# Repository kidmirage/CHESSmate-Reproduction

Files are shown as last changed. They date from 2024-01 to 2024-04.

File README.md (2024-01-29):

# CHESSmate-Reproduction
The plan is to make a reproduction of the dedicated chess computer CHESSmate released by Commodore in 1978.

CHESSmate was developed by Peter Jennings, author of the KIM-1 MicroChess program, under contract with Commodore International. The CHESSmate’s hardware is based on the venerable KIM-1, but the ROMs are loaded with a custom MicroChess 1.5 image not the KIM’s monitor.

CHESSmate units are extremely hard to find, understandable given that 45 years have passed since they were introduced. My hope is to build a working CHESSmate computer using modern fabrication techniques and components, and to produce a comprehensive set of instructions with modeling files (PCB, 3D Print, etc.) so that anyone else could make one as well.

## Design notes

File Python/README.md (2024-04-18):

This is a software only CHESSmate emulator written in Python. As far as I know the only dependency is that PyGame must be available. I have tested this on:

Raspberry Pi 4 - Python 3.11.2 - PyGame 2.1.2

Windows - Python 3.10.5 - PyGame 2.1.2

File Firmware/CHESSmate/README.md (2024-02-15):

This Arduino Pro Mini version of the CHESSmate emulator is officialy deprecated. The Arduino was just too slow.

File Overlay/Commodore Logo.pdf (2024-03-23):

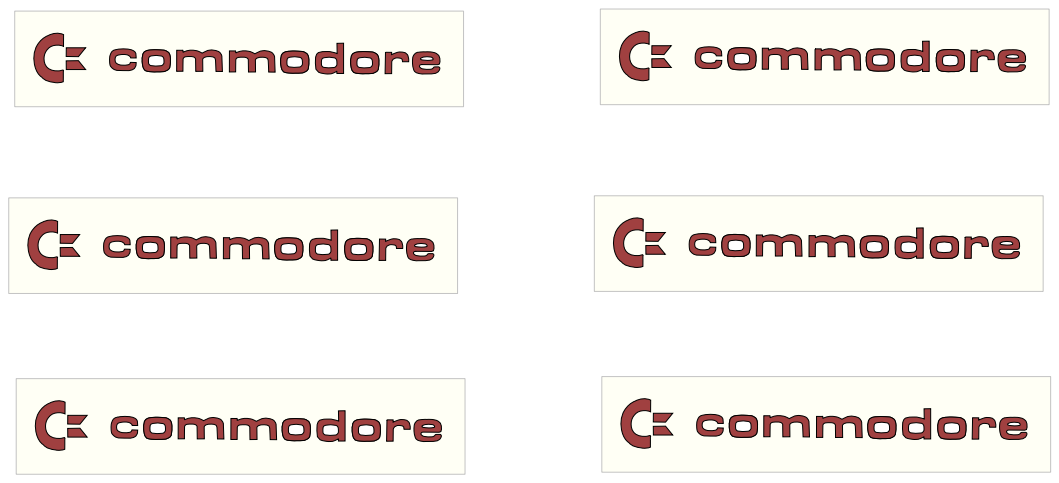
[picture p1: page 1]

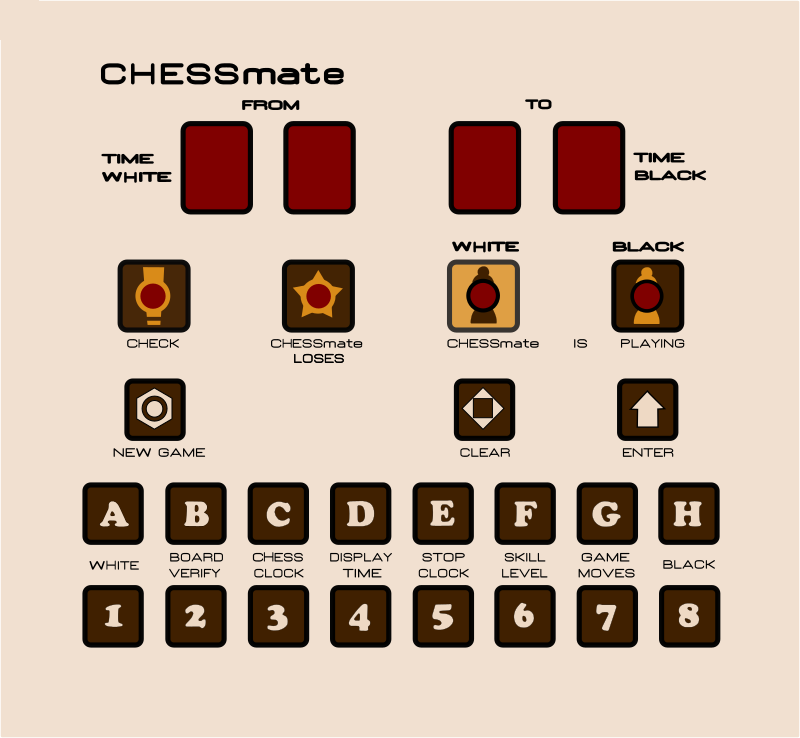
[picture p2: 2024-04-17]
Python/Images/Membrane Image (800x738).png

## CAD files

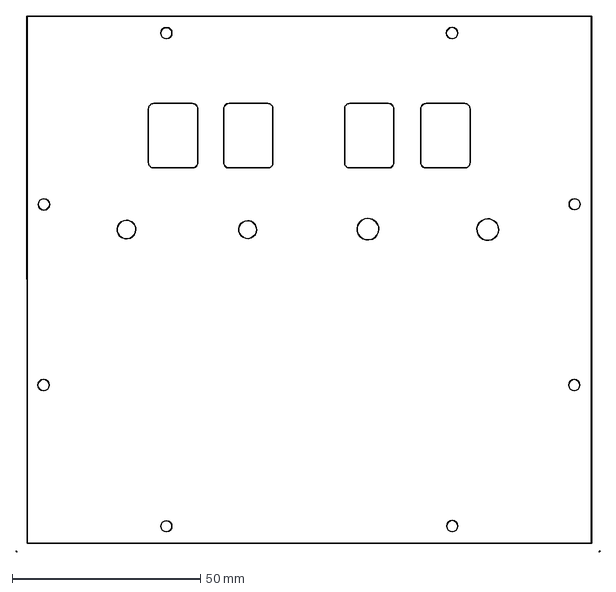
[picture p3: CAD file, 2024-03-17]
Models/CM_Chessmate Cutouts.dxf
155.2 x 142.4 mm

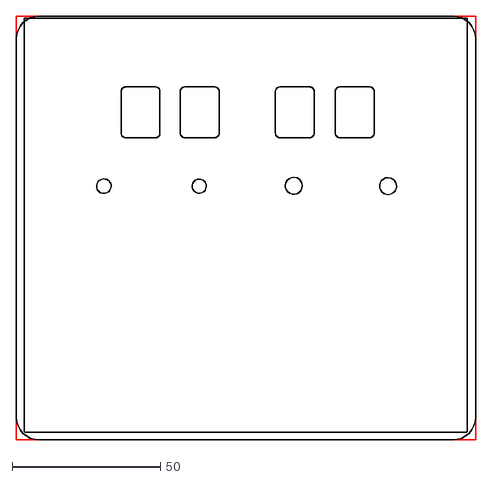
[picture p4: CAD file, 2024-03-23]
Overlay/Membrane Cutouts.dxf
155.2 x 143.0

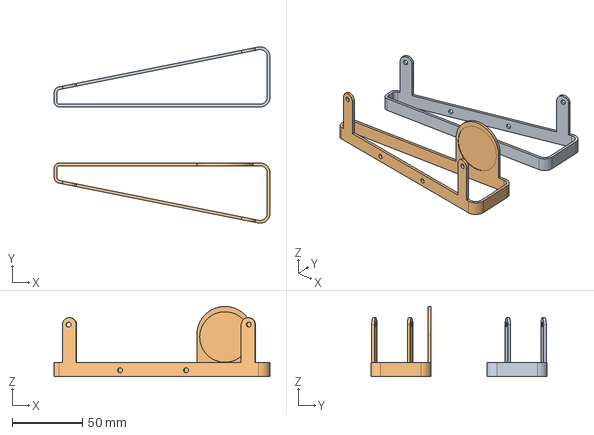
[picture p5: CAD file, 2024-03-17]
Models/CM_Minimal Stand 2.step
154.0 x 125.8 x 50.0 mm

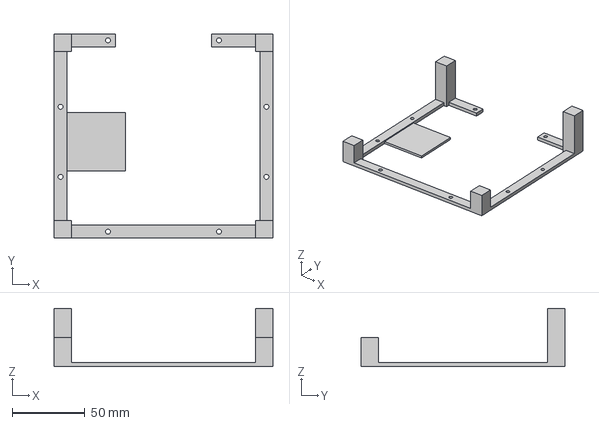
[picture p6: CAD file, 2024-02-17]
Models/CM_Minimal Stand.step
150.0 x 140.0 x 40.0 mm

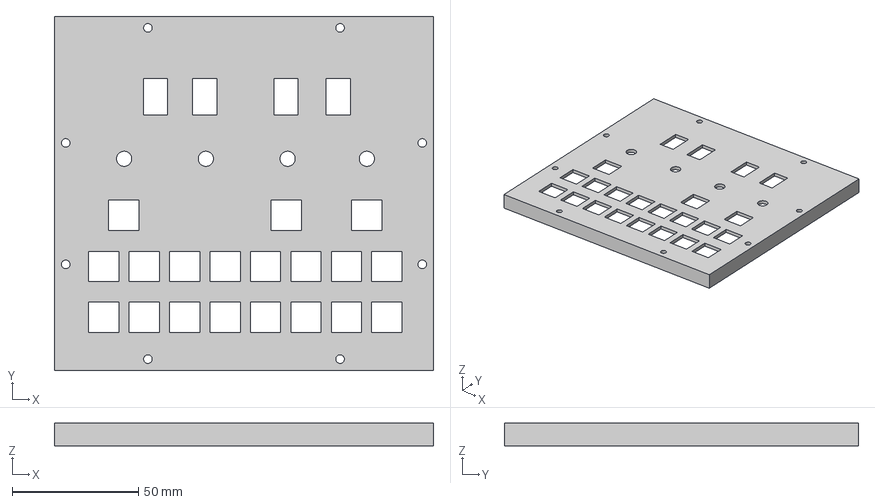
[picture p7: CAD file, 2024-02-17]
Models/CM_Membrane Standoff.step
150.0 x 140.0 x 9.00 mm

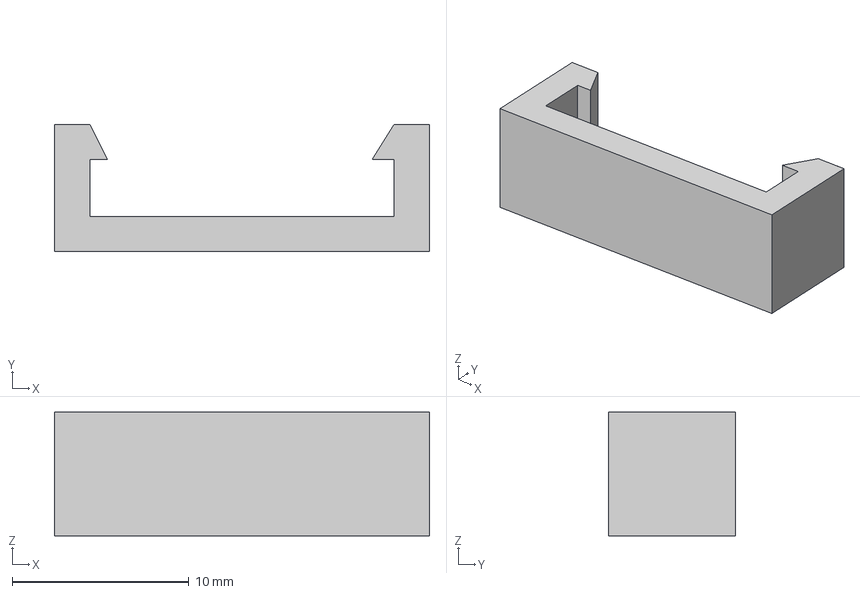
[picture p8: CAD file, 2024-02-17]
Models/CM_Power Clip.step
21.2 x 7.20 x 7.00 mm

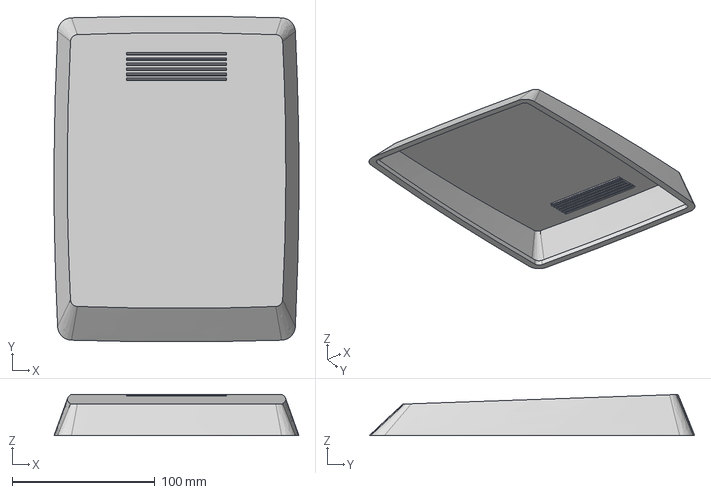
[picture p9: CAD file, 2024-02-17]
Models/CM_Case Bottom.step
171.4 x 227.7 x 28.7 mm

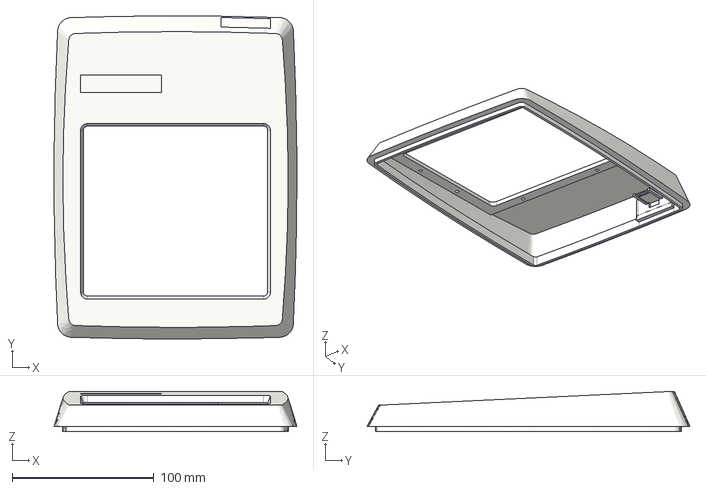
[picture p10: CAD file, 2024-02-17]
Models/CM_Case Top.step
171.3 x 227.9 x 28.6 mm

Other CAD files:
Models/CM_Case Bottom.3mf
Models/CM_Case Top.3mf
Models/CM_Membrane Standoff.3mf
Models/CM_Minimal Stand 2.3mf
Models/CM_Minimal Stand.3mf
Models/CM_Power Clip.3mf

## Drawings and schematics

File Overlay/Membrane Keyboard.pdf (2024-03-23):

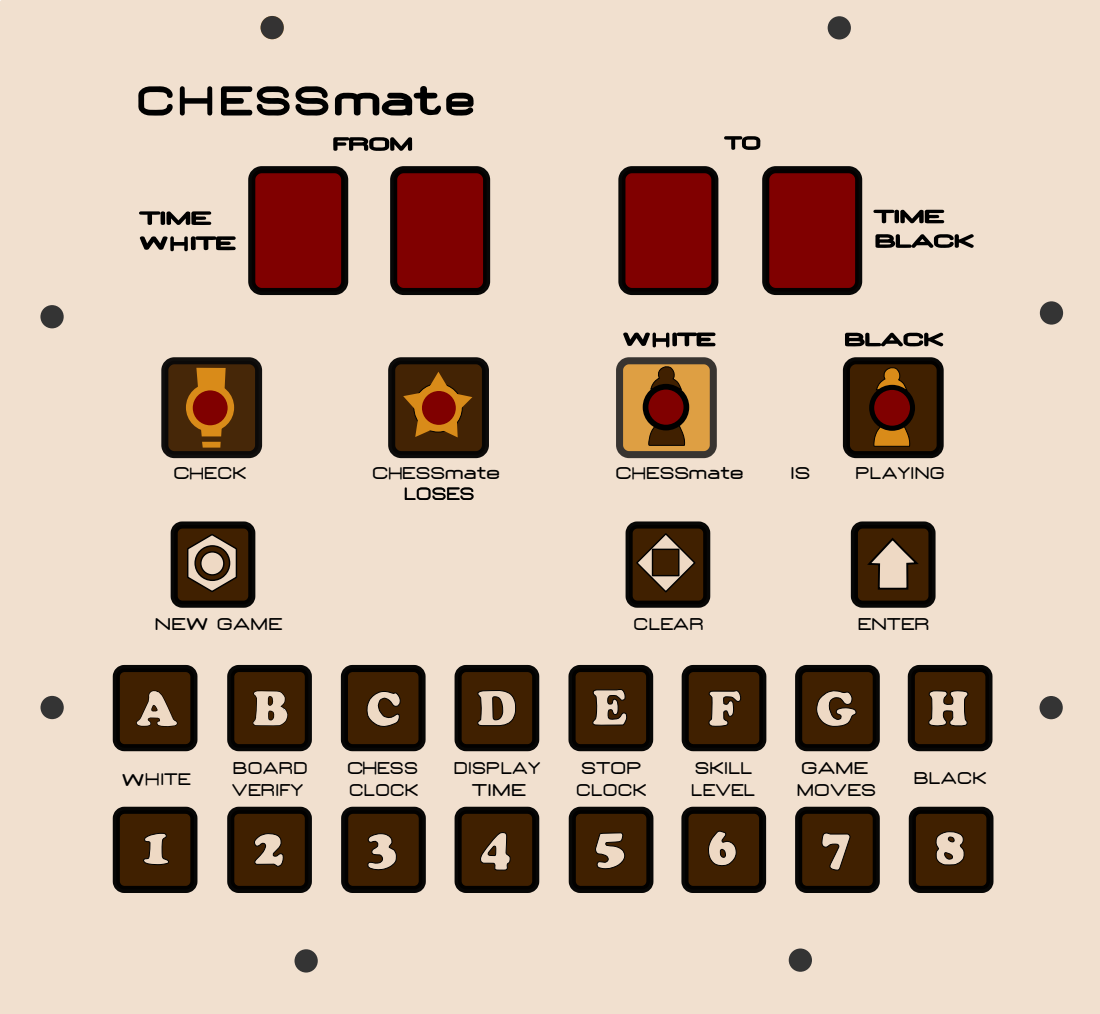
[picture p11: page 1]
WHITE; BOARD; VERIFY; CHESS CLOCK; DISPLAY TIME; STOP CLOCK; SKILL LEVEL; GAME; MOVES; BLACK; LOSES; CHECK; CHESSmate; NEW GAME; CLEAR; ENTER; PLAYING

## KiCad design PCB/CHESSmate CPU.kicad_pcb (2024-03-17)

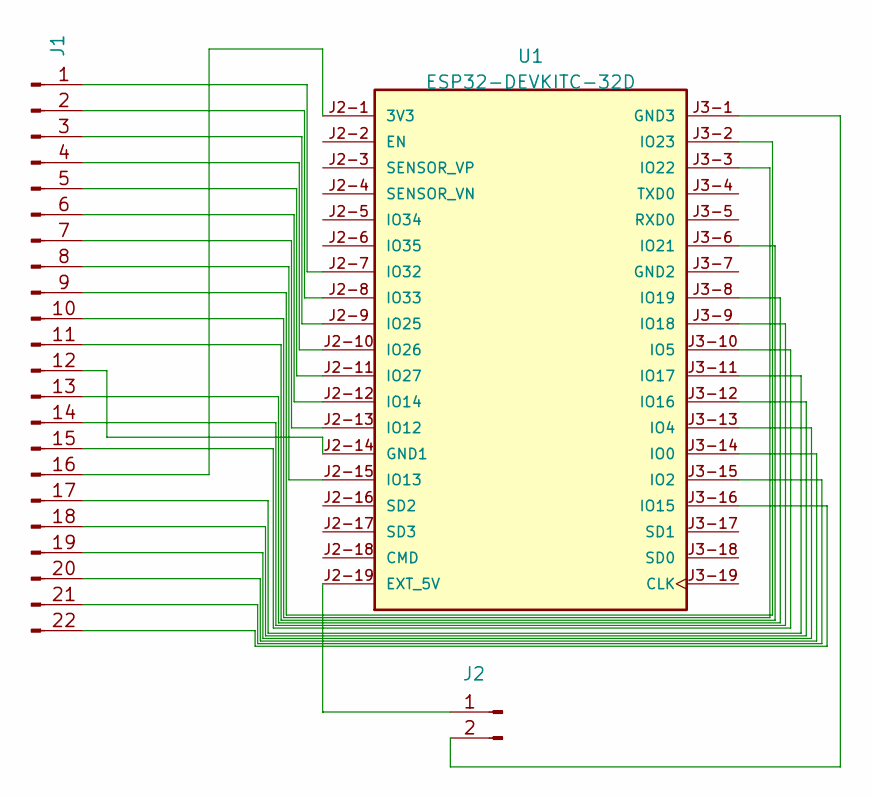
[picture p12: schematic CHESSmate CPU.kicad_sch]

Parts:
J1: Conn_01x22_Pin; PinHeader_1x22_P2.54mm_Vertical
J2: Conn_01x02_Pin; PinHeader_1x02_P2.54mm_Vertical
U1: ESP32-DEVKITC-32D; MODULE_ESP32-DEVKITC-32D; PARTREV V4

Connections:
unnamed: J1.1, U1.J2-7 (IO32)
unnamed: J1.2, U1.J2-8 (IO33)
unnamed: J1.3, U1.J2-9 (IO25)
unnamed: J1.4, U1.J2-10 (IO26)
unnamed: J1.5, U1.J2-11 (IO27)
unnamed: J1.6, U1.J2-12 (IO14)
unnamed: J1.7, U1.J2-13 (IO12)
unnamed: J1.8, U1.J2-15 (IO13)
unnamed: J1.9, U1.J3-2 (IO23)
unnamed: J1.10, U1.J3-3 (IO22)
unnamed: J1.11, U1.J3-6 (IO21)
unnamed: J1.12, U1.J2-14 (GND1)
unnamed: J1.13, U1.J3-8 (IO19)
unnamed: J1.14, U1.J3-9 (IO18)
unnamed: J1.15, U1.J3-10 (IO5)
unnamed: J1.16, U1.J2-1 (3V3)
unnamed: J1.17, U1.J3-11 (IO17)
unnamed: J1.18, U1.J3-12 (IO16)
unnamed: J1.19, U1.J3-13 (IO4)
unnamed: J1.20, U1.J3-14 (IO0)
unnamed: J1.21, U1.J3-15 (IO2)
unnamed: J1.22, U1.J3-16 (IO15)
unnamed: J2.1, U1.J2-19 (EXT_5V)
unnamed: J2.2, U1.J3-1 (GND3)

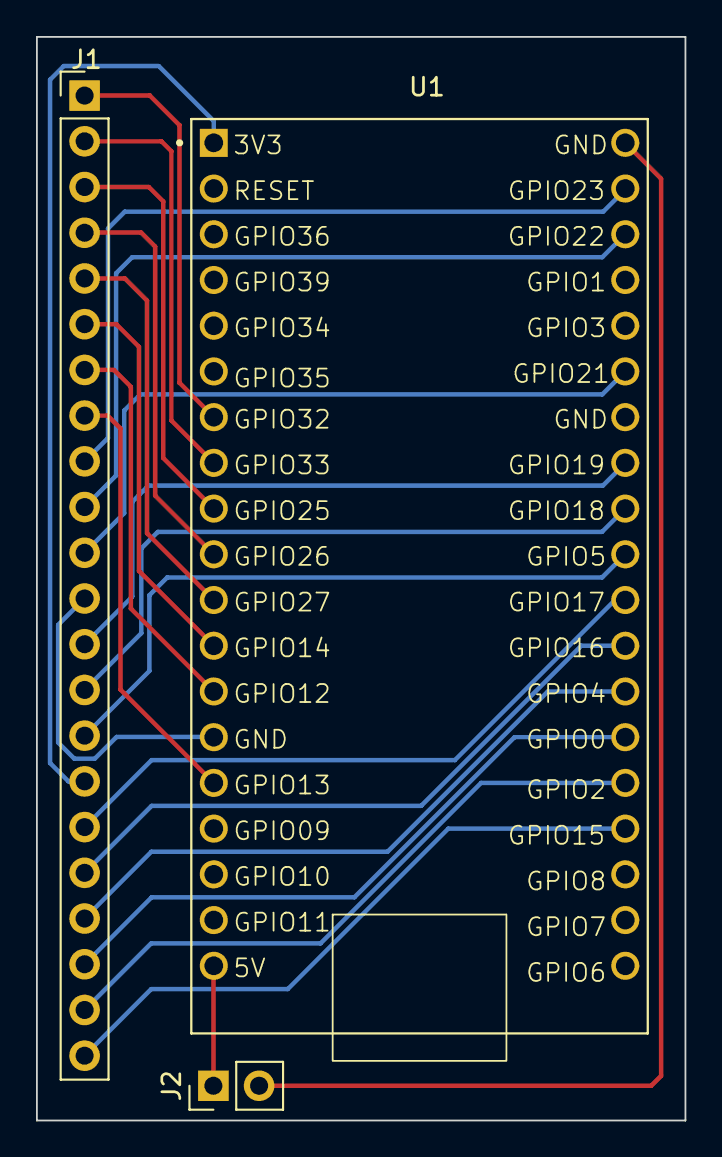
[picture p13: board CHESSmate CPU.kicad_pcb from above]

Board: 2 copper layers, 36.0 x 60.2 mm, 3 parts (0 on the bottom side), 24 nets.

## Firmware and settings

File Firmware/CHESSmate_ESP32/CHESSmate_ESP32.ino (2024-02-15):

/** CHESSmate emulator for Arduino.
 *  
 *  The 6502 emulator is from Mike Chambers.
 *
 *    http://forum.arduino.cc/index.php?topic=193216.0
 *
 *  Project inspired by Oscar Vermeulen's KIM-1 Uno project.
 *
 *    https://obsolescence.wixsite.com/obsolescence/kim-uno-summary-c1uuh
 *
 *  CHESSmate code added by Michael Gardi.
 *
 *    https://hackaday.io/project/194011-commodore-chessmate-reproduction
 *
 *  This Sketch is specifically for the ESP32 WROOM.
 */
#define SAD     0     // 6530 A DATA
#define PADD    1     // 6530 A DATA DIRECTION
#define SBD     2     // 6530 B DATA
#define PBDD    3     // 6530 B DATA DIRECTION
#define CLK1T   4     // DIV BY 1 TIME Read timer disable interrupt 
#define CLKRDT  6     // READ TIMER
#define CLKRDI  7     // READ TIMEOUT BIT
#define CKINT   14    // Read timer interrupt
#define CLKTI   15    // DIV by 1024 enable interrupts

// IO pins used on the arduino.
#define PA0 13
#define PA1 12
#define PA2 14
#define PA3 27
#define PA4 26
#define PA5 25
#define PA6 33
#define PA7 32

#define ENTER_KEY     23
#define CLEAR_KEY     22
#define NEW_GAME_KEY  21

#define CHECK_LED     19
#define LOSES_LED     18
#define B_W_LED       5

#define DISPLAY_1     17
#define DISPLAY_2     16
#define DISPLAY_3     4
#define DISPLAY_4     0

#define BUZZER_1      2
#define BUZZER_2      15

// Millisecond value for 1 minute.
#define PART_MINUTE   250   // 1/240th of a minute in millseconds.

// Keep track of what "virtual" keyboard row has been enabled.
int keyboard_row = 0;

// Remember what the last write to the SBC (B data port) was.
uint8_t sbc_value = 0;

// When this value is non-zero generate an interrupt after one minute passes.
unsigned long int_start = 0;

// This is the interrupt flag. 0x00 if no interrupt, 0x80 if interrupt has been triggered.
uint8_t int_flag = 0;

extern "C" { 
  void exec6502(int32_t tickcount);
  void reset6502();
  void irq6502();
  uint16_t getpc();
}

void setup () {
  Serial.begin (115200);
  while (!Serial) {
    ; // wait for serial port to connect. Needed for native USB
  }
  delay(100);
  Serial.println ("CHESSmate Starting");
  
  // Set modes for pins that won't change.
  pinMode(NEW_GAME_KEY, INPUT_PULLUP);
  pinMode(CLEAR_KEY, INPUT_PULLUP);
  pinMode(ENTER_KEY, INPUT_PULLUP);

  pinMode(CHECK_LED, OUTPUT);
  pinMode(LOSES_LED, OUTPUT);
  pinMode(B_W_LED, OUTPUT);

  pinMode(DISPLAY_1, OUTPUT);
  pinMode(DISPLAY_2, OUTPUT);
  pinMode(DISPLAY_3, OUTPUT);
  pinMode(DISPLAY_4, OUTPUT);

  pinMode(BUZZER_1, OUTPUT);
  pinMode(BUZZER_2, OUTPUT);

  // Set the program counter to the start of the CHESSmate program, set stack pointer, clear registers and flags.
  reset6502();
}

void loop () {
  // If timing is enabled, this value is in 6502 clock ticks.
  exec6502(1000);

  if (int_start > 0) {
    if ((millis() - int_start) >= PART_MINUTE) {
      int_flag = 0x80;
      irq6502();
    }
  }
}

// Required functions from the emulator C code.
extern "C" { 
  /********************************************************************************************
   *   This is the key part of the CHESSmate "emulation". Pretend to be a 6530-24 RRIOT chip.
   *
   *   Translate the reads and writes to and from the program to the 6530-24 RRIOT registers
   *   and map the bits to the actual switches, 7-segment displays, and LEDs.
   *
   ********************************************************************************************/
  // Handle reads from RRIOT registers.
  uint8_t readRRIOT(uint16_t address) {
    if (address == SBD) {             // Port B Data
      // Reading from PORTB. Return the previous value of PORTB.
      return sbc_value;
    } else if (address == SAD) {      // Port A Data
      // Check for NEW GAME. (Reset)
      if (digitalRead(NEW_GAME_KEY) == LOW) {
        reset6502();
      }
      // Default result, no keys pressed.
      uint8_t result = 0b01111111;
  
      // Checking for keypress.
      if (keyboard_row == 1) {
        if (digitalRead(PA7) == LOW) {
          result = 0b01011111;
        } else if (digitalRead(PA6) == LOW) {
          result = 0b01101111;
        } else if (digitalRead(PA5) == LOW) {
          result = 0b01110111;
        } else if (digitalRead(PA4) == LOW) {
          result = 0b01111011;
        } else if (digitalRead(PA3) == LOW) {
          result = 0b01111101;
        } else if (digitalRead(PA2) == LOW) {
          result = 0b01111110;
        }
      } else if (keyboard_row == 2) {
        if (digitalRead(PA1) == LOW) {
          result = 0b00111111;
        } else if (digitalRead(PA0) == LOW) {
          result = 0b01011111;
        } else if (digitalRead(CLEAR_KEY) == LOW) {
          result = 0b01101111;
        } else if (digitalRead(ENTER_KEY) == LOW) {
          result = 0b01110111;
        }
      }
      return result;
    } else if (address == CKINT) {
      // Read the RRIOT timer. Used to get a random number for opening moves.
      return random(0, 32);
    } else if (address == CLKRDI) {
      // Return 0x80 if the "interrupt" has been triggered, 0x00 otherwise.
      return int_flag;
    } else if (address == CLKRDT) {
      // Current value of the timer countdown?
      return 0x00;
    } 
  }

  // Handle writes to RRIOT registers.
  void writeRRIOT(uint16_t address, uint8_t value) {
    if (address == SAD) {                 // Port A Data
      // PA0 - PA7 Data Register (SAD)
      // Maps to Pro Mini pins 0 - 7
      if ((value & 0b00000001) > 0) {
        digitalWrite(PA0, HIGH);
      } else {
        digitalWrite(PA0, LOW);
      }
      if ((value & 0b00000010) > 0) {
        digitalWrite(PA1, HIGH);
      } else {
        digitalWrite(PA1, LOW);
      }
      if ((value & 0b00000100) > 0) {
        digitalWrite(PA2, HIGH);
      } else {
        digitalWrite(PA2, LOW);
      }
      if ((value & 0b00001000) > 0) {
        digitalWrite(PA3, HIGH);
      } else {
        digitalWrite(PA3, LOW);
      }
      if ((value & 0b00010000) > 0) {
        digitalWrite(PA4, HIGH);
      } else {
        digitalWrite(PA4, LOW);
      }
      if ((value & 0b00100000) > 0) {
        digitalWrite(PA5, HIGH);
      } else {
        digitalWrite(PA5, LOW);
      }
      if ((value & 0b01000000) > 0) {
        digitalWrite(PA6, HIGH);
      } else {
        digitalWrite(PA6, LOW);
      }
      if ((value & 0b10000000) > 0) {
        digitalWrite(PA7, HIGH);
      } else {
        digitalWrite(PA7, LOW);
      }
      // Check for CHESSmate LOSES.
      if ((value & 0b10000000) > 0) {
        digitalWrite(LOSES_LED, HIGH);
      } else {
        digitalWrite(LOSES_LED, LOW);
      }
    } else if (address == PADD) {          // Port A Data Direction
      // PA0 - PA7 Data Direction Register (PADD)
      if (value == 128) {
        pinMode(PA0, INPUT_PULLUP);
        pinMode(PA1, INPUT_PULLUP);
        pinMode(PA2, INPUT_PULLUP);
        pinMode(PA3, INPUT_PULLUP);
        pinMode(PA4, INPUT_PULLUP);
        pinMode(PA5, INPUT_PULLUP);
        pinMode(PA6, INPUT_PULLUP);
        pinMode(PA7, INPUT_PULLUP);
      } else {
        pinMode(PA0, OUTPUT);
        pinMode(PA1, OUTPUT);
        pinMode(PA2, OUTPUT);
        pinMode(PA3, OUTPUT);
        pinMode(PA4, OUTPUT);
        pinMode(PA5, OUTPUT);
        pinMode(PA6, OUTPUT);
        pinMode(PA7, OUTPUT);;
      }
    } else if (address == SBD) {          // Port B Data
      // PB0 - PB7 Data Register (SBD)
      // Remember the last value written to this register.
      sbc_value = value;
  
      // The bottom 3 bits of the value control 8 IO lines. Only 1 will be turned on.
      digitalWrite(DISPLAY_1, LOW);
      digitalWrite(DISPLAY_2, LOW);
      digitalWrite(DISPLAY_3, LOW);
      digitalWrite(DISPLAY_4, LOW);
      keyboard_row = 0;
      digitalWrite(BUZZER_1, LOW);
      digitalWrite(BUZZER_2, LOW);
  
      // Determine which line to enable.
      switch (value & 0x07) {
        case 0:
          digitalWrite(DISPLAY_1, HIGH);
          break;
        case 1:
          digitalWrite(DISPLAY_2, HIGH);
          break;
        case 2:
          digitalWrite(DISPLAY_3, HIGH);
          break;
        case 3:
          digitalWrite(DISPLAY_4, HIGH);
          break;
        case 4:
          keyboard_row = 1;
          break;
        case 5:
          keyboard_row = 2;
          break;
        case 6:
          digitalWrite(BUZZER_1, HIGH);
          break;
        case 7:
          digitalWrite(BUZZER_2, HIGH);
          break;
        default:
          break;
      }
      // Check for CHECK.
      if ((value & 0b00001000) > 0) {
          digitalWrite(CHECK_LED, HIGH);
      } else {
          digitalWrite(CHECK_LED, LOW);
      }
      // Check for BLACK or WHITE.
      if ((value & 0b00010000) > 0) {
        digitalWrite(B_W_LED, LOW);
      } else {
        digitalWrite(B_W_LED, HIGH);
      }
    } else if (address == PBDD) {            // Port B Data Direction
      // PB0 - PB7 Data Direction Register (PBDD)
      // Does not directly map to specific pins. Will always be output. 0x7F
    } else if (address == CLKTI) {
      // Restart timer interrupt. 
      int_start = millis();
      int_flag = 0;
    } else if (address == CLK1T) {
      // Disable interrupts.
      int_start = 0;
    } 
  }
  extern "C" { 
    void printhex(uint16_t val) {
      Serial.print(val, HEX);
      Serial.print(" ");
      Serial.print(val);
      Serial.println();
    }
    void print_instruction(char r_w, uint16_t pc, uint16_t address, uint8_t val) {
      Serial.print(r_w);
      Serial.print(" ");
      Serial.print(pc,HEX);
      Serial.print(" ");
      Serial.print(address,HEX);
      Serial.print(" ");
      Serial.print(val,HEX);
      Serial.println();
    }
  }
} 

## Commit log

2024-01-29 Add files via upload
    KiCad files for the latest version of the CHESSmate PCB. Note that the schematic is a little out of date w.r.t. the PCB. Will fix.
    [CHESSmate PCB.kicad_pcb, CHESSmate PCB.kicad_sch]
2024-01-29 Add files via upload
    KiCad for latest PCB.
    [CHESSmate PCB.kicad_pcb, CHESSmate PCB.kicad_sch]
2024-01-29 Add files via upload
    Gerber files for producing a CHESSmate PCB.
    [CHESSmate PCB-B_Cu.gbl, CHESSmate PCB-B_Mask.gbs, CHESSmate PCB-B_Paste.gbp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]
2024-01-29 Add files via upload
    Arduino Sketch for CHESSmate targeted at an Arduino Pro Mini.
2024-01-31 Add files via upload
    Updated to latest version of schematic.
    [CHESSmate PCB.kicad_sch]
2024-02-05 Add files via upload
    Added CHESSmate code that runs on the ESP32.
2024-02-13 Add files via upload
    Added daughter board PCB to hold the ESP-32 WROOM.
    [CHESSmate CPU-B_Cu.gbl, CHESSmate CPU-B_Mask.gbs, CHESSmate CPU-B_Paste.gbp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]
2024-02-17 Add files via upload
    Added the Fusion 360 case models.
    [CM_Case Bottom.3mf, CM_Case Top.3mf, CM_Membrane Standoff.3mf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]
2024-02-17 Add files via upload
    Added the STEP files too.
    [CM_Case Bottom.step, CM_Case Top.step, CM_Membrane Standoff.step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]
2024-02-26 Add files via upload
    Fix for the CHESSmate CPU backpack daughter board.
    [CHESSmate CPU-B_Cu.gbl, CHESSmate CPU-B_Mask.gbs, CHESSmate CPU-B_Paste.gbp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]
2024-03-17 Add files via upload
    A second minimal stand.
    [CM Minimal Stand 2.3mf, CM Minimal Stand 2.step]
2024-03-17 Add files via upload
    DXF file used to create membrane mask.
    [CM_Chessmate Cutouts.dxf]
2024-03-17 Update and rename CM Minimal Stand 2.step to CM_Minimal Stand 2.step
    [CM_Minimal Stand 2.step]
2024-03-17 Rename CM Minimal Stand 2.3mf to CM_Minimal Stand 2.3mf
    [CM_Minimal Stand 2.3mf]
2024-03-17 Add files via upload
    CPU backpack daughter board.
    [CHESSmate CPU.kicad_pcb, CHESSmate CPU.kicad_sch]
2024-03-17 Rename CHESSmate.zip to CHESSmate PCB.zip
    Rename for consistency.
2024-03-23 Add files via upload
    Added membrane fabrication files.
    [Membrane Cutouts.dxf]
2024-03-23 Add files via upload
    Switched to printing orientation.
    [CM_Case Bottom.3mf, CM_Case Top.3mf, CM_Membrane Standoff.3mf]
2024-04-18 Create README.md
    This is a software only CHESSmate emulator written in Python. As far as I know the only dependency is that PyGame must be available. I have tested this on:
    Raspberry Pi 4 - Python 3.11.2 - PyGame 2.1.2
    Windows - Python 3.10.5 - PyGame 2.1.2
